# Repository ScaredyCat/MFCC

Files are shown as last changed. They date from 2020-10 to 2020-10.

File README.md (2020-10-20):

# MFCC
My first Clock Controller - My Corona Virus lockdown project (2020 - just in case there's another outbreak)

I was furloughed during 2020 and legally wasn't allowed to work for my employer so I took the time to try and learn somthing new. That turned out to be this project, learning how to use Kicad and how to build a radio-time enabled clock. Most of the things I've built in the past don't survive for too long, the Arduino is invariably repurposed for the next project and so on. This time it was different.

# Before we start

Most of this is really new to me. I've never designed a circuit board of any real complexity before this and I wouldn't particularly trust that my electronics knowledge is any use at all.

I've made some modifications to both the MSFDecoder library and the JQ6500 library so they are included here for completeness.

# Board

I used a DIYMORE Arduino Leonardo Clone for this project they are half the price of a Genuine Arduino Leonardo and have pins broken out to header pins in addition to the standard headers. The also have GND and 5v broken out for each pin and additional header pins for serial and i2c. This is really the sort of connectivity that I think should be on the genuine boards, but I guess they have reasons for not doing it.

The "motherboard" is really a deliberately oversized Arduino shield but it removes a lot of the wires and provides a stable platform for all the components. I appreciate my soldering leaves a lot to be desired. I used pin headers quite a bit for my connections just for convenience - they turned out to be inconvenient when wires kept popping out of them. Many of the connections do not get populated as they are for other options.

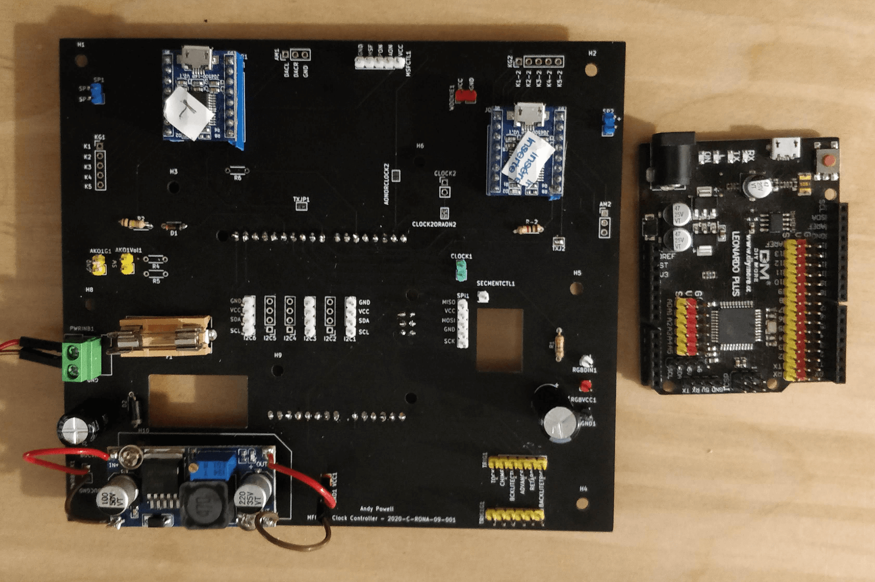
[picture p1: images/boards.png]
Image of boards


# Modules

The design is fairly modular and uses off the shelf modules to provide additional features. Prices at time of purchase (May-Oct 2020)

 - I2C:  LCD Display, Non volatile memory (EEPROM), DS3231
 - SPI:  7 Segment displays

 Major parts:

- 2 x JQ6500 for audio - if you don't want audio or only want chimes or only want tick-tock then it's up to you. Approx cost from aliexpress is £1/unit

- 2 x 7 segment display boards 0.56" 8 displays on a board Approx cost from aliexpress is £1.40/unit dependant on colour selected.

- 1 x LCD display with backpack Approx cost from aliexpress is £5/unit

- 1 x DS3231 module Approx cost from aliexpress is £0.90/unit

- 1 x buck converter for power Approx cost from aliexpress is £1/unit

- 1 x MSF receiver (CANADUINO) £11.18 + shipping (£5.40) - cost more than the price of getting the "motherboard" made, takes a long time to arrive. No other suppliers found as alternative. This can be swapped out for the DCF77 board if you want to use the DCF77 time signal (code changes required, same price
though)

- LED strip of WS2812B I picked up a 1 metre strip with 60 leds on it for £4.25 from aliexpress.

- Various header pins and headers these work out at about £0.15 each from aliexpress but I just got a box of them from an Amazon seller.

- An old (or new) quartz clock mechanism.

- PCB cost￡9.85 + ￡5.22 shipping that's for the minimum quantity of 5 boards.

You can get these parts at places like amazon for slightly inflated prices but without the 2 week wait - sometimes prices are the same so shop around.

Without access to something like [JLCPCB](https://jlcpcb.com/) [No, they didn't sponsor me] none of this would have really happened - it would have been another rats nest of wires project that survived for a limited time before repurposing the Arudino. Access to services like this make a huge difference to people starting out and the existance of software like [kICad](https://kicad-pcb.org/) makes the process of design to physical board simple. How many newbies would fork out £100's for pcb design software if they were just trying something out? KiCad is free and it's awesome and major component suppliers support the library format too.

# Issues

The biggest issue you are going to face is getting a good signal from Anthorn (Cumbria) - (or your location for WWVB, JJY). My workspace/office has lots of electrical equipment in it which interferes with the signal. Nothing during the day (the sun buggers up the signal) but better at night in with the receiver near a window. The antenna should be at 90 degrees to the expected signal path for best reception. Rotating it 90 degrees can change the signal level by 20-30dB. Initially my results were great but they have got steadily worse with a sync taking place maybe twice a fortnight if I'm lucky.

Having tweaked the MSFDecoder to cut down on noise thigs have got much better, not a lot of syncing during the day but occasioanal ones and quite a lot of syncing at night/early morning. I'm getting multiple syncs a day.

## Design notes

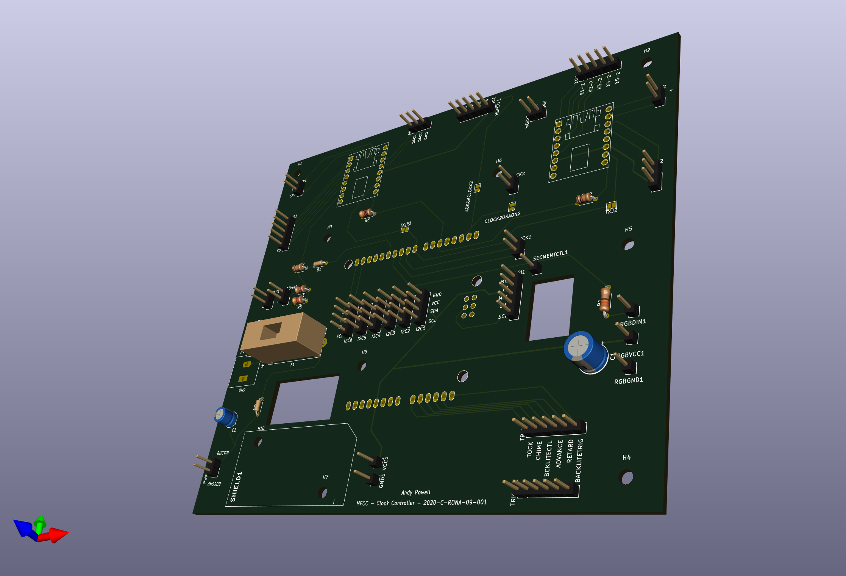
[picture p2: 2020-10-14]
images/ClockBoard.png

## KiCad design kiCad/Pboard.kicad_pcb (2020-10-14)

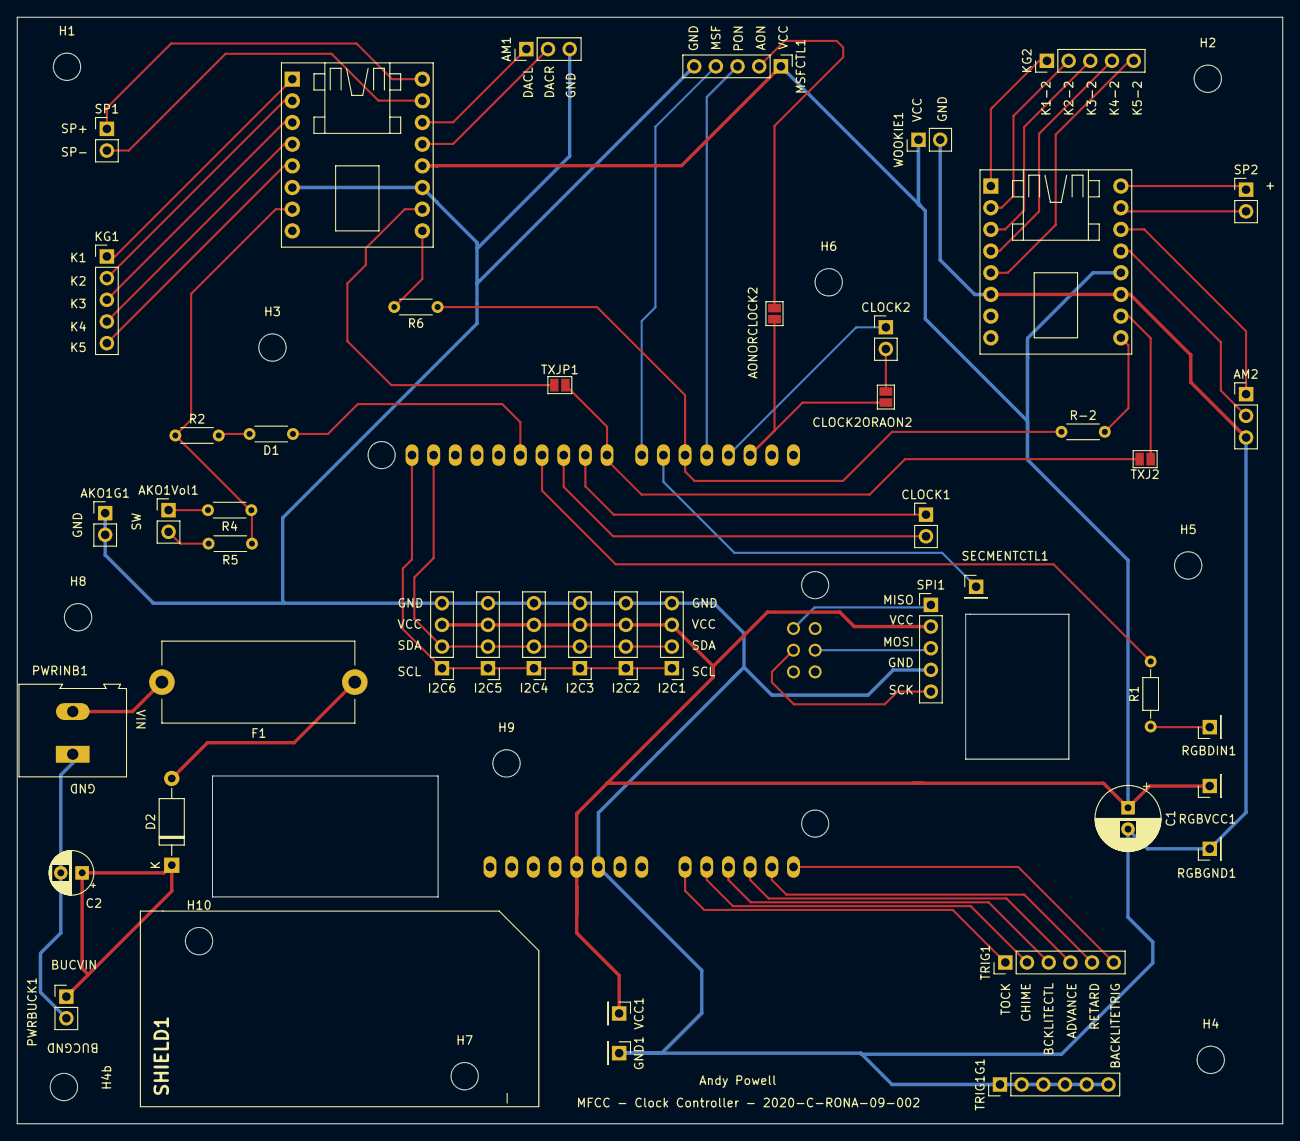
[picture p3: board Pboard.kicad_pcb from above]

Board: 2 copper layers, 148.3 x 129.7 mm, 58 parts (0 on the bottom side), 57 nets.

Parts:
AKO1G1, AKO1Vol1: Conn_01x02; PinHeader_1x02_P2.54mm_Vertical
AM1, AM2: Amp; PinHeader_1x03_P2.54mm_Vertical
AONORCLOCK2: SolderJumper_2_Open; SolderJumper-2_P1.3mm_Open_Pad1.0x1.5mm
C1: 1000uF; CP_Radial_D7.5mm_P2.50mm
C2: 4.7; CP_Radial_D5.0mm_P2.50mm
CLOCK1, CLOCK2: Conn_01x02; PinHeader_1x02_P2.54mm_Vertical
CLOCK2ORAON2: SolderJumper_2_Open; SolderJumper-2_P1.3mm_Open_Pad1.0x1.5mm
D1: D; R_Axial_DIN0204_L3.6mm_D1.6mm_P5.08mm_Horizontal
D2: D; D_A-405_P10.16mm_Horizontal
F1: 3A; Fuseholder_Cylinder-5x20mm_Stelvio-Kontek_PTF78_Horizontal_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
GND1: Conn_01x01; PinHeader_1x01_P2.54mm_Vertical
H1, H2, H3, H4, H4b, H5, H6, H7, H8, H9, H10: MountingHole; MountingHole_3.2mm_M3
I2C1, I2C2, I2C3, I2C4, I2C5, I2C6: Conn_01x04; PinHeader_1x04_P2.54mm_Vertical
KG1, KG2: Keys; PinHeader_1x05_P2.54mm_Vertical
MSFCTL1: Conn_01x05; PinHeader_1x05_P2.54mm_Vertical
PWRBUCK1: Conn_01x02; PinHeader_1x02_P2.54mm_Vertical
PWRINB1: Screw_Terminal_01x02; TerminalBlock_Altech_AK300-2_P5.00mm
R1: 330; R_Axial_DIN0204_L3.6mm_D1.6mm_P7.62mm_Horizontal
R2: 100K; R_Axial_DIN0204_L3.6mm_D1.6mm_P5.08mm_Horizontal
R4: 6.2k; R_Axial_DIN0204_L3.6mm_D1.6mm_P5.08mm_Horizontal
R5: 3.3K; R_Axial_DIN0204_L3.6mm_D1.6mm_P5.08mm_Horizontal
R6: R1K; R_Axial_DIN0204_L3.6mm_D1.6mm_P5.08mm_Horizontal
R-2: R1K; R_Axial_DIN0204_L3.6mm_D1.6mm_P5.08mm_Horizontal
RGBDIN1: Conn_01x01; PinHeader_1x01_P2.54mm_Vertical
RGBGND1: Conn_01x01; PinHeader_1x01_P2.54mm_Vertical
RGBVCC1: Conn_01x01; PinHeader_1x01_P2.54mm_Vertical
SECMENTCTL1: Conn_01x01; PinHeader_1x01_P2.54mm_Vertical
SHIELD1: ARDUINO_SHIELD
SP1, SP2: Speaker; PinHeader_1x02_P2.54mm_Vertical
SPI1: Conn_01x05; PinHeader_1x05_P2.54mm_Vertical
TRIG1, TRIG1G1: Conn_01x06; PinHeader_1x06_P2.54mm_Vertical
TXJ2: SolderJumper_2_Open; SolderJumper-2_P1.3mm_Open_Pad1.0x1.5mm
TXJP1: SolderJumper_2_Open; SolderJumper-2_P1.3mm_Open_Pad1.0x1.5mm
U1, U2: JQ6500-16P_Module; JQ6500_2x8_P2.54mm
VCC1: Conn_01x01; PinHeader_1x01_P2.54mm_Vertical
WOOKIE1: Conn_01x02; PinHeader_1x02_P2.54mm_Vertical

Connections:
ADKEY: R2.1, R4.1, R5.1, U2.7
ADVANCE: SHIELD1.AD3, TRIG1.4
AON: AONORCLOCK2.2, MSFCTL1.2
BCKLITETRIG: SHIELD1.AD5, TRIG1.6
CHIMES: SHIELD1.AD1, TRIG1.2
CLOCKA: CLOCK1.1, SHIELD1.9
CLOCKB: CLOCK1.2, SHIELD1.10
CLOCKC: CLOCK2.1, SHIELD1.3
CLOCKD: CLOCK2.2, CLOCK2ORAON2.2
DACL: AM1.1, U2.14
DACL-2: AM2.1, U1.14
DACR: AM1.2, U2.13
DACR-2: AM2.2, U1.13
GND: AKO1G1.1, AKO1G1.2, AM1.3, AM2.3, C1.2, GND1.1, I2C1.4, I2C2.4, I2C3.4, I2C4.4, I2C5.4, I2C6.4, MSFCTL1.5, RGBGND1.1, SHIELD1.GND1, SPI1.4, TRIG1G1.1, TRIG1G1.2, TRIG1G1.3, TRIG1G1.4, TRIG1G1.5, TRIG1G1.6, U1.6, U1.11, U2.6, U2.11, WOOKIE1.2
INGND: C2.2, PWRBUCK1.2, PWRINB1.1
JQRX: R6.1, R-2.1, SHIELD1.5
JQTICKTOCK: D1.1, SHIELD1.12
JQTX: SHIELD1.8, TXJ2.2, TXJP1.2
K1: KG1.1, U2.1
K1-2: KG2.1, U1.1
K2: KG1.2, U2.2
K2-2: KG2.2, U1.2
K3: KG1.3, U2.3
K3-2: KG2.3, U1.3
K4: KG1.4, U2.4
K4-2: KG2.4, U1.4
K5: KG1.5, U2.5
K5-2: KG2.5, U1.5
LCDBACKLIGHT: SHIELD1.AD2, TRIG1.3
LEDDATA: R1.2, SHIELD1.11
MISO-NR: SHIELD1.SP1, SPI1.1
MOSI-NR: SHIELD1.SP4, SPI1.3
MSF: MSFCTL1.4, SHIELD1.7
unnamed: AKO1Vol1.1, R4.2
unnamed: AKO1Vol1.2, R5.2
unnamed: AONORCLOCK2.1, CLOCK2ORAON2.1, SHIELD1.2
unnamed: D1.2, R2.2
unnamed: D2.2, F1.1
unnamed: F1.2, PWRINB1.2
unnamed: R1.1, RGBDIN1.1
PBVCC: C2.1, D2.1, PWRBUCK1.1
PON: MSFCTL1.3, SHIELD1.4
RETARD: SHIELD1.AD4, TRIG1.5
RX: R6.2, U2.9
RX-2: R-2.2, U1.9
SCK-NR: SHIELD1.SP3, SPI1.5
SCL: I2C1.1, I2C2.1, I2C3.1, I2C4.1, I2C5.1, I2C6.1, SHIELD1.SCL
SDA: I2C1.2, I2C2.2, I2C3.2, I2C4.2, I2C5.2, I2C6.2, SHIELD1.SDA
SEGMENT: SECMENTCTL1.1, SHIELD1.6
SPK+: SP1.1, U2.16
SPK+-2: SP2.1, U1.16
SPK-: SP1.2, U2.15
SPK--2: SP2.2, U1.15
TICKTOCK: SHIELD1.AD0, TRIG1.1
TX: TXJP1.1, U2.10
TX-2: TXJ2.1, U1.10
VCC: C1.1, I2C1.3, I2C2.3, I2C3.3, I2C4.3, I2C5.3, I2C6.3, MSFCTL1.1, RGBVCC1.1, SHIELD1.5V, SPI1.2, U1.12, U2.12, VCC1.1, WOOKIE1.1

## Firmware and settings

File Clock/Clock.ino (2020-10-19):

/*
    I've Got A Big Clock - inspired by Brett Oliver's creations.

    Corona virus lockdown project

    Andy Powell, in the year of the virus, 2020.

    PIN Allocation
    ========================================================
    2   AON/CLOCKD/HUMAN  - Either AON (MSF Autogain on) or CLOCKD. CLOCKC and CLOCKD or human detection
                          - WARNING DS3231 library uses pins 2/3 - either don't use this lib or don't
                          - use AON/CLOCKD/HUMAN
    3   CLOCKC            - add the pontential to have another clock mechanism
    4   PON               - Power up for MSF board
    5   JQ6500            - (1/4, 1/2, 3/4  hour and top of the hour chimes)
    6   MAX7219_CS        - Drive 7 segment led arrays via SPI
    7   INTERRUPT 4       - Interrupt for MSF receiver
    8   JQ6500            - Software serial port for JQ6500 #2 to trigger chimes
    9   CLOCKA            - Drive pin for quartz clock requires 2 pins
    10  CLOCKB            - sending alternating pulses, 30ms pulse for 120ms
    11  LED_PIN           - For control of LED strip for notification LEDs.
    12  AUTOTOCK          - Hardware loop to JQ6500 #1 for repeated Tick-Tock.
    A0  TICKTOCKSWITCH    - Enable or disable tick-tock sound from JQ6500 #1
    A1  CHIMESWITCH       - Enable or disable 1/4 hour and hourly chimes from JQ6500 #2
    A2  BACKLIGHT_PIN     - Allows us to turn the LCD backlight on or off. Any value < 128 = Off
    A3  ADVANCE_PIN       - momentary switch turns advance on.
    A4  RETARD_PIN        - Momentary switch to retard pulses.
    A5  BACKLIGHT_TRIGGER - Force backlight on or off


    I2C:  LCD Display, Non volatile memory, DS3231
    SPI:  7 Segment displays

*/
#include <TimeLib.h>
#include <Adafruit_NeoPixel.h>
#include <MSFDecoder.h>
#include <Wire.h>
#include <SoftwareSerial.h>
#include <JQ6500_Serial.h>
#include <LiquidCrystal_I2C.h>
#include <SPI.h>
#include <DS3231.h>

/*
    Clock pins for clock 1
    Multiple clocks can be used and hands removed that are
    not required, ie you can have a mechanism with just a
    second hand. Nothing really needs to change because
    they all take a pule to move a second's worth.
*/

const int CLOCKA = 9;         // Main analog clock pins
const int CLOCKB = 10;        // for alternate pulses.

/*
    Switches to disable or enable sounds and the backlight

*/
const int TICKTOCKSWITCH = A0;
const int CHIMESWITCH = A1;
const int BACKLIGHT_PIN = A2;
const int ADVANCE_PIN = A3;
const int RETARD_PIN = A4;
const int BACKLIGHT_TRIGGER = A5;
const int PON = 4;


/*
   Using a CANADUINO Atomic Clock AM Receiver that works with MSF
   in the UK. The other option in DCF77 where the signal originates
   from Germany. Canaduino has pathetic wires that will break. I'd advise hot gluing
   the board and antenna to a lump of wood the size of Canada so that it doesn't
   move aboot.

   MSF library needs an interrupt. This depends on the device being used and how many
   interrupts you have

   PON is a pin to allow powering the board on and off but in this instance power is
   'plentiful' so not required and we need the pins anyway.


*/


/*
    Arduino Interrupt Number:   0   1   2   3   4   5   6   7   8   9   10    11  12  13  14  15  16
    UNO I/O Pins                2   3           7
    LEONARDO                    3   2   0   1   -1  -1  7
    Mega2560 I/O Pins           2 3 21  20  19  18
    ESP8266 GPIO Pins           0 1 2 3 4 5             12  13  14  15  16

      Leonardo interrupt pins

      PIN D0 (rx) D1 (tx) D2  D3  D7
      INT   2       3     1    0  6

      PCINT (Pin Change)

      PIN     8   9   10    11
      PCINT   4   5   6      7
*/

uint8_t parity = 0;

/*

   MAX7219 driven 7 segment LED controller

*/

#define Number_MAX7219 2            // 2 chips = 16 digits
#define MAX7219_CS  6               // pin the MAX7219's CS pin is connected to
#define Default_Brightness 0        // brightness level 0-15

#include <MAX7219_8_Digit_Driver.h>

/*
    DS3231 for managing the time and keeping it stored in event of
    a power failure.
*/
#define disk1 0x57 // The 32k storage on the DS3231 board.
#define DS3231_I2C_ADDRESS 0x68
#include <DS3231.h>
DS3231 Clock(SDA, SCL);

/*
    CLOCK_MINUTE values correspond with their id on
    the JQ6500 which is used to trigger audio playback

*/

const int CLOCK_15_MINUTE = 13;
const int CLOCK_30_MINUTE = 14;
const int CLOCK_45_MINUTE = 15;
const int CLOCK_00_MINUTE = 16;

const int twoSecondPulse = 12;

/*
    States of the sounds and backlight
*/
bool soundTickTock = true;
bool soundChime = true;
bool backlightState = true;
bool goDark = false;
bool isDark = false;
bool savedBacklightState = false;
bool refreshTime = true;

/*
      Trial and error values for each quartz clock
      mechanism

     int cwPulse   = 220;               // CW pulse width
     int cwPeriod  = 20;               // CW pulse interval
     int ccwPulse   = 120;               // CW pulse width
     int ccwPeriod  = 20;               // CW pulse interval
*/

const int clockwise = 30;
const int anticlockwise = 20;
const int minimumInterval = 40;   // minimum between pulses to prevent stalling.
boolean flag = false;             // drive polarity flag - toggle for each pulse


#if defined(ARDUINO) && ARDUINO >= 100
#define printByte(args)  write(args);
#else
#define printByte(args)  print(args,BYTE);
#endif

/*
    Hard to test if you haven't got a clock
    unixtime for testing
*/

const unsigned long DEFAULT_TIME = 1599231660;

/*
    Keep track of the time values, we only
    need to do things when there's a change
*/
int oldH, oldM, oldS, oldD, oldMo, oldY, oldW;

/*
   Avoid doing things the first time round
   everything gets setup nicely.
*/
bool firstRun = true;

/*
   If we need to change the time we can do it by
   either retarding (holding back on pulses) or
   by advancing (adding more frequent pulses)
   to adjust the time.

*/
bool retard = false;
int retardCount = 0;

bool advance = false;
int advanceCount = 0;

bool bstChangeForwardNow = false;
bool bstChangeBackwardNow = false;
const int bstTicks = 3600 + 720;  // 1 hour plus the time taken to advance an hour
const int bstRetards = 3600;
bool bstChanged = false;
bool bst = false;
bool bstsoon = false;
bool syncd = false;

/*
    Display setup for LCD. We don't have a
    last time we had a signal from MSF until
    we've run setup. Parity doesn't matter
    until we try to get a signal.
*/
char LastMSFLCD[21] = "00:00:00 00-00-00";
char parityReason[21] = "";
/*
   Rather than use multiple LEDs on pins or a matrix
   I went for an RGB strip. They cost almost nothing
   and you can cut off as many as you need and use them
   Arduino has happily run with 8 LEDS with no issues at all
   but I run then at less than a 10th of maximum brightness.

   However I will be using an external power source for these
   on the complete project because I plan on using them to indicate
   days of the week, months, week number etc

   They're indicator leds not a light show.

   Define what pin they're connected to and how many of them there
   are.
*/
#define   LED_PIN   11
#define   LED_COUNT 35
/*
   Parity Error LEDs
*/
#define   LED_PARITYERROR_YEAR 31
#define   LED_PARITYERROR_MONTH 32
#define   LED_PARITYERROR_WEEKDAY 33
#define   LED_PARITYERROR_TIME 34



/*
   Months of the year LEDs
*/

#define   LED_MONTH_JANUARY 19
#define   LED_MONTH_FEBRUARY 20
#define   LED_MONTH_MARCH 21
#define   LED_MONTH_APRIL 22
#define   LED_MONTH_MAY 23
#define   LED_MONTH_JUNE 24
#define   LED_MONTH_JULY 25
#define   LED_MONTH_AUGUST 26
#define   LED_MONTH_SEPTEMBER 27
#define   LED_MONTH_OCTOBER 28
#define   LED_MONTH_NOVEMBER 29
#define   LED_MONTH_DECEMBER 30

/*
   Days of the week LEDs.
   The numbers represent their location on the
   LED strip. Sunday is day 0. So we just need to
   add 10 to the day of the week value to get its
   location for lighting the LED
*/

#define   LED_DOW_SUNDAY 12
#define   LED_DOW_MONDAY 13
#define   LED_DOW_TUESDAY 14
#define   LED_DOW_WEDNESDAY 15
#define   LED_DOW_THURSDAY 16
#define   LED_DOW_FRIDAY 17
#define   LED_DOW_SATURDAY 18

#define   LED_MIRROR 11
#define   LED_SYNC_TODAY 10

#define   TICKTOCK 9
#define   CHIMING 8

#define   LED_BSTSOON 7
#define   LED_SUMMERTIME 6
#define   LED_MSFCARRIER 5
#define   VALID_MSFTIME 4
#define   SECOND_TICK 3
#define   LED_RETARD 2
#define   LED_ADVANCE 1
#define   LED_TICK 0

#define MAX_BRIGHTNESS 10

const uint8_t lcdbell[8]  = {0x4, 0xe, 0xe, 0xe, 0x1f, 0x0, 0x4};
const uint8_t lcdnote[8]  = {0x2, 0x3, 0x2, 0xe, 0x1e, 0xc, 0x0};
const uint8_t lcdclock[8] = {0x0, 0xe, 0x15, 0x17, 0x11, 0xe, 0x0};
const uint8_t lcdheart[8] = {0x0, 0xa, 0x1f, 0x1f, 0xe, 0x4, 0x0};
const uint8_t lcdblank[8]  = {0x0, 0x0, 0x0, 0x0, 0x0, 0x0, 0x0};
const uint8_t lcdcheck[8] = {0x0, 0x1, 0x3, 0x16, 0x1c, 0x8, 0x0};
const uint8_t lcdcross[8] = {0x0, 0x1b, 0xe, 0x4, 0xe, 0x1b, 0x0};
const uint8_t lcdretarrow[8] = {  0x1, 0x1, 0x5, 0x9, 0x1f, 0x8, 0x4};


MSFDecoder MSF;

const byte aInputPin = 7;
const byte aInterrupt = 4;

byte MSFIcon[] = { B00000,  B00000,  B00000,  B01010,  B10101,  B00000,  B00000,  B00000};

static const uint32_t YELLOW = 0xFFCC00;
static const uint32_t RED    = 0xff0d00;
static const uint32_t GREEN  = 0x73ff00;
static const uint32_t WHITE  = 0xffffff;
static const uint32_t ORANGE = 0xff9900;
static const uint32_t PURPLE = 0x80098E;
static const uint32_t BLACK  = 0x000000;
static const uint32_t OFF    = 0x000000;
static const uint32_t BLUE   = 0x0B5394;
static const uint32_t MAGENTA = 0xFF00FF;


unsigned long pulses = 0;

bool g_bPrevCarrierState;
byte g_iPrevBitCount;

bool tick = false;
bool stopClock = false;
bool century = false;
bool ghourFormat12 = false;
bool writtenToday = false;
bool writtenThisHour = false;

byte iBitCount = 0;
bool bCarrierState = false;
byte savedHour, savedMinute, savedSecond, savedDay, savedMonth, savedYear;
Time tinfo;


const char* weekDay[8] = {  "Sun", "Mon", "Tue", "Wed", "Thu", "Fri", "Sat", "Sun"};
const char* months[13] = {"", "Jan", "Feb", "Mar", "Apr", "May", "Jun", "Jul", "Aug", "Sep", "Oct", "Nov", "Dec"};
const char* parityErrors[5] = { "No Errors", "Year Error", "Month Error", "Weekday Error", "Time Error"};

Adafruit_NeoPixel strip(LED_COUNT, LED_PIN, NEO_GRB + NEO_KHZ800);
LiquidCrystal_I2C lcd = LiquidCrystal_I2C(0x27, 20, 4);

// make an instance of MAX7219_Digit called My_Display and set CS pin

MAX7219_8_Digit_Driver My_Display(MAX7219_CS, Number_MAX7219);

JQ6500_Serial mp3(8, 5);


void setup() {

  pinMode(PON, OUTPUT);
  digitalWrite(PON, LOW);

  pinMode(TICKTOCKSWITCH, INPUT_PULLUP);
  pinMode(CHIMESWITCH, INPUT_PULLUP);
  pinMode(ADVANCE_PIN, INPUT_PULLUP);
  pinMode(RETARD_PIN, INPUT_PULLUP);
  pinMode(BACKLIGHT_TRIGGER, INPUT_PULLUP);
  pinMode(twoSecondPulse, OUTPUT);

  Wire.begin();

  g_bPrevCarrierState = false;
  g_iPrevBitCount = 255;

  digitalWrite(13, LOW);
  
  My_Display.String_To_Buffer(" ", 0);

 //Serial.begin(115200);
 //while (!Serial);
 

  MSF.init(aInputPin, aInterrupt);

  Clock.begin();

  strip.begin();           // INITIALIZE NeoPixel strip object (REQUIRED)
  strip.show();            // Turn OFF all pixels ASAP
  strip.setBrightness(MAX_BRIGHTNESS); // Set BRIGHTNESS to about 1/5 (max = 255)

  pinMode(CLOCKA, OUTPUT);
  pinMode(CLOCKB, OUTPUT);
  digitalWrite(CLOCKA, LOW);
  digitalWrite(CLOCKB, LOW);

  tinfo = Clock.getTime();
  setTime(tinfo.hour, tinfo.min, tinfo.sec, tinfo.date, tinfo.mon, tinfo.year);

  mp3.begin(9600);
  mp3.reset();
  mp3.setVolume(27);
  mp3.setLoopMode(MP3_LOOP_NONE);

  readSavedDate(savedHour, savedMinute, savedSecond, savedDay, savedMonth, savedYear);
  sprintf(LastMSFLCD, "%02d:%02d:%02d %02d-%02d-%02d", savedHour, savedMinute, savedSecond, savedDay, savedMonth, savedYear);

  g_bPrevCarrierState = false;
  g_iPrevBitCount = 255;

  lcd.init();                      // initialize the lcd
  lcd.setBacklight(HIGH);
  //lcd.createChar(6, lcdcross);
  lcd.createChar(0, lcdbell);
  lcd.createChar(1, lcdnote);
  lcd.createChar(2, lcdclock);
  lcd.createChar(3, lcdheart);
  lcd.createChar(4, lcdblank);
  lcd.createChar(5, lcdcheck);
  lcd.createChar(6, MSFIcon);
  lcd.createChar(7, lcdretarrow);
  lcd.home();
  lcd.setCursor(15, 0);
  lcd.printByte(3);

  if (soundTickTock) {
    lcd.setCursor(16, 0);
    lcd.printByte(0);
  } else {
    lcd.setCursor(16, 0);
    lcd.printByte(4);
  }
  if (soundChime) {
    lcd.setCursor(17, 0);
    lcd.printByte(1);
  } else {
    lcd.setCursor(17, 0);
    lcd.printByte(4);
  }
  if (advance) {
    lcd.setCursor(18, 0);
    lcd.printByte(2);
  } else {
    lcd.setCursor(18, 0);
    lcd.printByte(4);
  }
  if (retard) {
    lcd.setCursor(19, 0);
    lcd.printByte(7);
  } else {
    lcd.setCursor(19, 0);
    lcd.printByte(4);
  }

  lcd.setCursor(0, 1); lcd.printByte(2);
  lcd.setCursor(0, 2); lcd.printByte(6);

  /* backlight off for startup */
  pinMode(BACKLIGHT_PIN, OUTPUT);
  analogWrite(BACKLIGHT_PIN, 0);

}


// Main loop
void loop() {


  if (firstRun) {
    oldM = minute();
    oldH = hour();
    oldY = year();
    dayOfWeekLED(weekday());
    monthOfYearLED(month());
    firstRun = false;
  }

  bCarrierState = MSF.getHasCarrier();
  iBitCount = MSF.getBitCount();


  if (MSF.TimeAvailable) {

    parity = MSF.ParityResult;

    if ( parity == 0) {

      // write it to DS3231
      if (MSF.m_iYear < 2000)
        Clock.setDate(MSF.m_iDay, MSF.m_iMonth, 2000 + MSF.m_iYear);
      else
        Clock.setDate(MSF.m_iDay, MSF.m_iMonth, MSF.m_iYear);

      Clock.setTime(MSF.m_iHour, MSF.m_iMinute, 0);
      Clock.setDOW(MSF.m_iDOW);

      if (MSF.m_iYear < 2000)
        setTime(MSF.m_iHour, MSF.m_iMinute, 0, MSF.m_iDay, MSF.m_iMonth, MSF.m_iYear);
      else
        setTime(MSF.m_iHour, MSF.m_iMinute, 0, MSF.m_iDay, MSF.m_iMonth, 2000 + MSF.m_iYear);

      Clock.setDate(day(), month(), year());


      /*
          This will serve as "The last date signal received history.
          We'll load this into LastMSFLCD when the arduino restarts.

         This is EEPROM so if our signal is "too good" we want to prevent writing to this constantly

      */
      if (!writtenThisHour) {
        writeSavedDate(MSF.m_iHour, MSF.m_iMinute, 0, MSF.m_iDay, MSF.m_iMonth, MSF.m_iYear);
        writtenThisHour = true;
      }
      
      writtenToday = true;
      
      bst = MSF.m_BST;
      bstsoon = MSF.m_BSTSOON;

      indicatorLED(LED_SUMMERTIME, YELLOW, OFF, bst);
      indicatorLED(LED_BSTSOON, YELLOW, OFF, bstsoon);

      sprintf(LastMSFLCD, "%02d:%02d:%02d %02d-%02d-%02d", hour(), minute(), 0, day(), month(), year() - 2000);
      syncd = true;

      indicatorLED(LED_SYNC_TODAY, BLUE, OFF, syncd);

    /*  indicatorLED(LED_PARITYERROR_YEAR, YELLOW, OFF, false);
      indicatorLED(LED_PARITYERROR_MONTH, YELLOW, OFF, false);
      indicatorLED(LED_PARITYERROR_WEEKDAY, YELLOW, OFF, false);
      indicatorLED(LED_PARITYERROR_TIME, YELLOW, OFF, false);
    */
     

      /*
         Automatically retard time if we're changing to winter
         time.
      */

      if (MSF.m_BST && MSF.m_BSTSOON && !bstChanged) {
        retardCount = bstRetards;
        retard = true;
        stopClock = true;
        bstChanged = true;
      }

      /*
         Automatically advance time if we're changing to summer
         time.
      */

      if (!MSF.m_BST && MSF.m_BSTSOON && !bstChanged) {
        advanceCount = bstTicks;
        advance = true;
        bstChanged = true;
      }

      dayOfWeekLED(weekday());
      monthOfYearLED(month());

    } else {

      if (parity > 0) {
        indicatorLED(30 + parity, RED, OFF, true);
      }
    }

    MSF.TimeAvailable = 0;
  } else {

    // doing this makes me vomit a little each time I see it.
    // but it does 'fix' the issue.

    tinfo = Clock.getTime();
    setTime(tinfo.hour, tinfo.min, tinfo.sec, tinfo.date, tinfo.mon, tinfo.year);
  }

  indicatorLED(LED_MIRROR, MAGENTA, OFF, !MSF.LED);
  
  // Freeze time for all events
  // so that all tested events are for the same point in time.
  
  time_t timeNow = now(); 
  
  tasksOnceASecond(timeNow);

  if (retard || bstChangeBackwardNow) {
    if (retardCount > 0) {
      if (oldS != second(timeNow) ) {
        oldS = second(timeNow);
        retardCount--;
      }

    } else {
      retard = false;
      bstChangeBackwardNow = false;
      stopClock = false;
      retardCount = 0;
      lcdindicatorLED(LED_RETARD, retard);
      indicatorLED(LED_RETARD, PURPLE, OFF, retard);

    }
    displayTime(goDark, timeNow);
  }

  if (advance || bstChangeForwardNow) {
    if (advanceCount > 0) {
      delay(minimumInterval);
      motorPulse(clockwise);
      advanceCount--;
      //sprintf(parityReason,"% 10d",bstTicks-advanceCount);
    } else {
      advance = false;
      bstChangeForwardNow = false;
      advanceCount = 0;
      lcdindicatorLED(LED_ADVANCE, advance);
      indicatorLED(LED_ADVANCE, GREEN, OFF, advance);

    }
    displayTime(goDark, timeNow);

  }

} // loop

void indicatorLED(int c, uint32_t onColour, uint32_t offColour, bool state) {

  if (!goDark) {

    if (isDark) {
      strip.setBrightness(MAX_BRIGHTNESS);
      isDark = false;
    }

  } else {
    //strip.setPixelColor(c, OFF);
    strip.setBrightness(0);
    isDark = true;
  }
  
  // Set these regardless of brightness otherwise DOW/MONTH wont change 
  // if we're in lightsOut mode.
  
    if (state)
      strip.setPixelColor(c, onColour); // Set pixel 'c' to value 'color'
    else
      strip.setPixelColor(c, offColour); // Set pixel 'c' to value 'color'

  strip.show();

}


void displayTime(bool lightsOut, time_t frozenTime) {

  char timeDisplay[22];
  char timeDisplayLCD[22];

  int year2d =year(frozenTime);

  if (year2d > 2000)
    year2d = year2d-2000;


  if (second() % 3 == 0) {
    //indicatorLED(LED_ADVANCE, GREEN, OFF, true);
    sprintf(timeDisplay, "%02d-%02d-%02d%02d-%02d-%02d",  hour(frozenTime),  minute(frozenTime),  second(frozenTime),  day(frozenTime),  month(frozenTime),  year2d);
    sprintf(timeDisplayLCD, "%02d:%02d:%02d %02d-%02d-%02d", hour(frozenTime),  minute(frozenTime),  second(frozenTime),  day(frozenTime),  month(frozenTime),  year2d);
  } else {
    //indicatorLED(LED_ADVANCE, GREEN, OFF, false);
    sprintf(timeDisplay, "%02d %02d %02d%02d-%02d-%02d", hour(frozenTime),  minute(frozenTime),  second(frozenTime),  day(frozenTime),  month(frozenTime),  year2d);
    sprintf(timeDisplayLCD, "%02d %02d %02d %02d-%02d-%02d", hour(frozenTime),  minute(frozenTime),  second(frozenTime),  day(frozenTime),  month(frozenTime),  year2d);
  }

  char dy[3] = "";

  sprintf(dy, "%2d", day());

  if (lightsOut || backlightState) {
    if (lightsOut)
      sprintf(timeDisplay, "%8 ");
    lcd.noDisplay();
  } else {
    lcd.display();
  }

  My_Display.String_To_Buffer(timeDisplay, 0);

  sprintf(parityReason, "  %02d of 60 Pulses", iBitCount);

  say(4, 1, parityReason, false);
  say(2, 3, timeDisplayLCD, false);
  say (3, 3, LastMSFLCD, false);
  say(1, 1, weekDay[weekday() - 1], false);
  say(1, 5, dy, false);
  say(1, 8, months[month()], false);

}

void checkSwitches() {

  soundTickTock = !digitalRead(TICKTOCKSWITCH);
  soundChime = !digitalRead(CHIMESWITCH);
  backlightState = digitalRead(BACKLIGHT_TRIGGER);
  advance = !digitalRead(ADVANCE_PIN);
  retard = !digitalRead(RETARD_PIN);

  if (advance) {
    //advance = digitalRead(ADVANCE_PIN);
    lcdindicatorLED(LED_ADVANCE, advance);
    indicatorLED(LED_ADVANCE, GREEN, OFF, advance);
    advanceCount = 5;
  }

  if (retard) {
    lcdindicatorLED(LED_RETARD, retard);
    indicatorLED(LED_RETARD, PURPLE, OFF, true);
    retardCount = 5;
    stopClock = true;
  }

  lcdindicatorLED(TICKTOCK, soundTickTock);
  lcdindicatorLED(CHIMING, soundChime);

  indicatorLED(TICKTOCK, WHITE, OFF, soundTickTock);
  indicatorLED(CHIMING, WHITE, OFF, soundChime);

  if (backlightState || goDark)
    analogWrite(BACKLIGHT_PIN, 0);
  else
    analogWrite(BACKLIGHT_PIN, 128);

}

void chime(int chimeId) {

  if (!goDark)
    mp3.playFileByIndexNumber(chimeId);

}


void monthOfYearLED(int m) {

  for (int i = 0; i <= 11; i++) {
    if (m == i)
      strip.setPixelColor(i + LED_MONTH_JANUARY, GREEN);
    else
      strip.setPixelColor(i + LED_MONTH_JANUARY, OFF);
  }

  strip.show();

}

void dayOfWeekLED(int DOW) {

  // Days of week, unlike linux, don't start at 0.  
  
  for (int i = 0; i <= 6; i++) {
    if (DOW-1 == i)       
      strip.setPixelColor(i + LED_DOW_SUNDAY, GREEN);
     else 
      strip.setPixelColor(i + LED_DOW_SUNDAY, OFF);
 
  }

  strip.show();

}

void lcdindicatorLED(int item, bool state) {

  switch (item) {
    case SECOND_TICK:
      lcd.setCursor(15, 0);
      if (state) {
        lcd.printByte(3);
      } else {
        lcd.printByte(4);
      }
      break;
    case TICKTOCK:
      lcd.setCursor(16, 0);
      if (state) {
        lcd.printByte(0);
      } else {
        lcd.printByte(4);
      }
      break;
    case CHIMING:
      lcd.setCursor(17, 0);
      if (state) {
        lcd.printByte(1);
      } else {
        lcd.printByte(4);
      }
      break;
    case LED_ADVANCE:
      lcd.setCursor(18, 0);
      if (state) {
        lcd.printByte(2);
      } else {
        lcd.printByte(4);
      }
      break;
    case LED_RETARD:
      lcd.setCursor(19, 0);
      if (state) {
        lcd.printByte(7);
      } else {
        lcd.printByte(4);
      }
      break;
  }
}
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

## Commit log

2020-10-14 Modified libraries used
    Libraries with modifications.
    JQ6500 doesn't wait for completion of audio, we just want it triggered and then forgotten about.
    I've added BST, BST Change and LED mirror to MSFDecoder.
2020-10-14 KiCad data and code commit
    Need to tidy up the code quite a bit. Trying to be good and document stuff.
2020-10-14 Move files
    Peobably help if I put the files in the right place.
    [Pboard.kicad_pcb, Pboard.sch]
2020-10-14 "FIx" time loss
    Increase the minimum PULSE_IGNORE_WIDTH to 80 to try and remove noise
    [Clock.ino]
2020-10-15 Removed big issue text
    Refining code to ignore short pulses, removing getting temperature from DS3231 every second tweaking display options to use saved time rather than using second() etc re-reading the time - thanks to "cattledog" for spotting that.
2020-10-17 Fix displayed time bug
    Freezing the second caused unexpected corruption of data of lcd and 7 segment displays.
    [Clock.ino]
